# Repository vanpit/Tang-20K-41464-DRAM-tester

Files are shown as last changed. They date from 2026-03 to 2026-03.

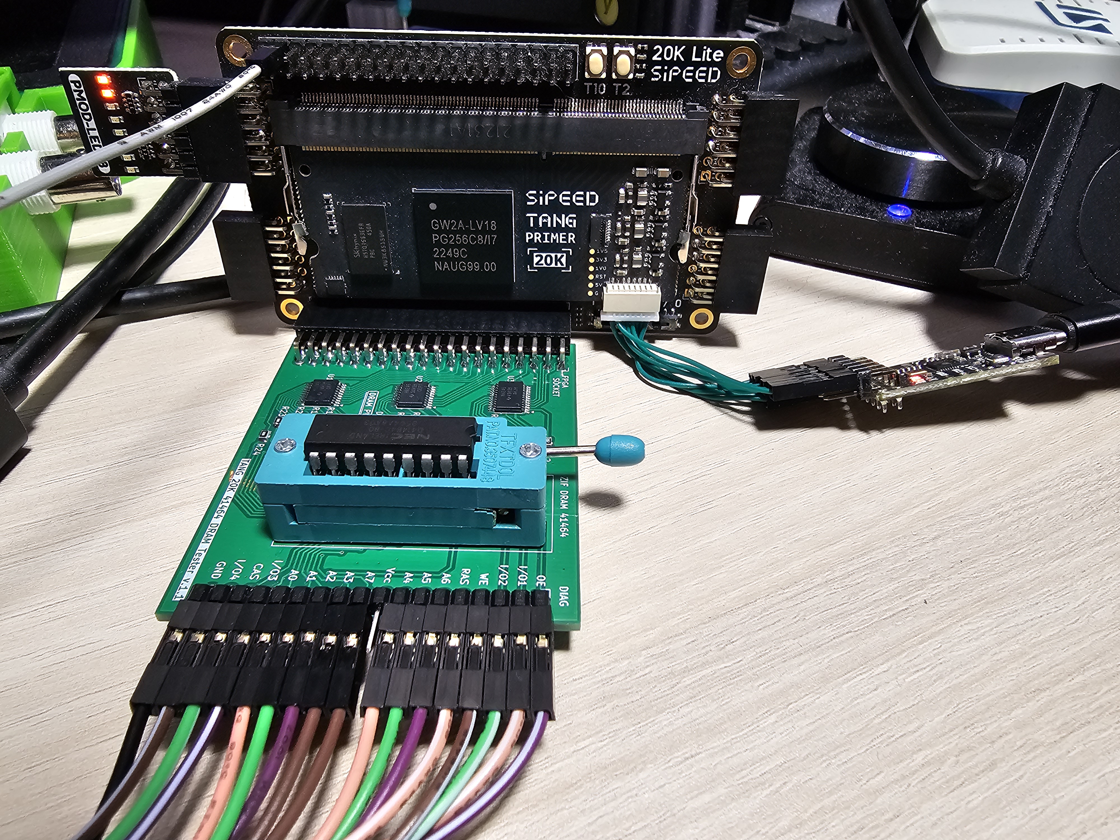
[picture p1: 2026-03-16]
Pictures/20260316_213214.jpg

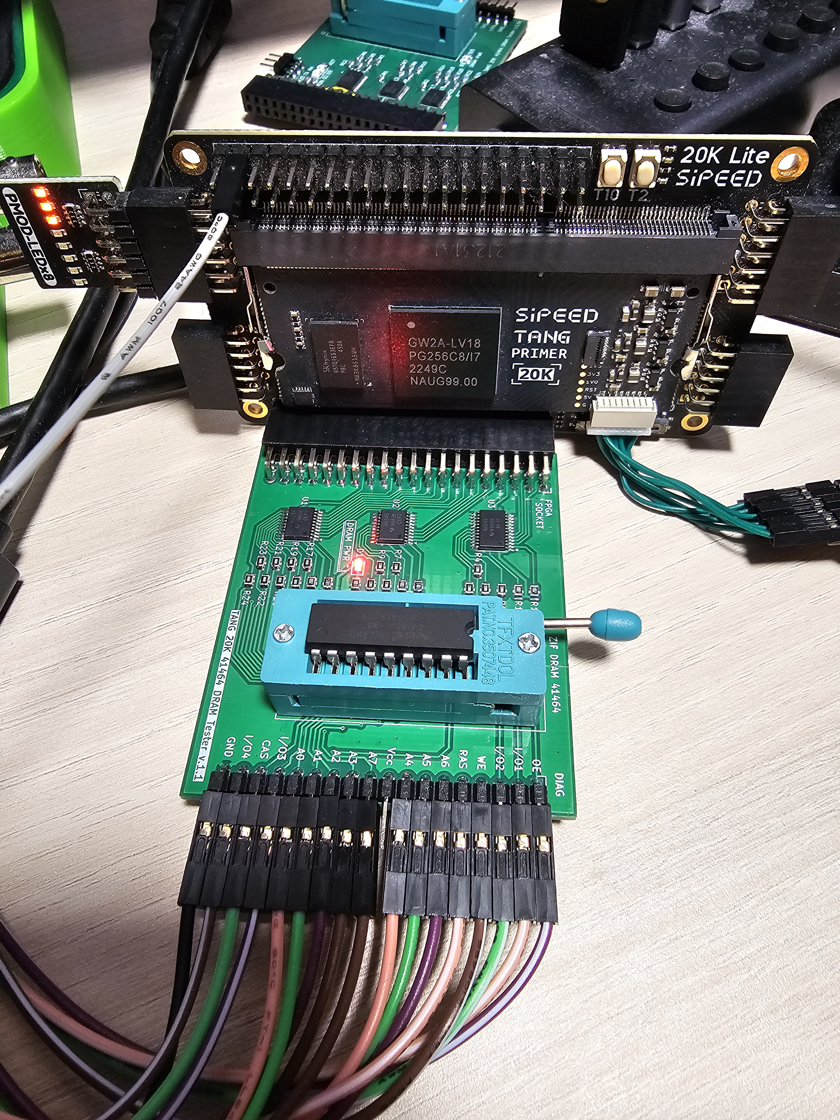
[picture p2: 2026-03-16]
Pictures/20260316_213205.jpg

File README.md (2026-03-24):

Tang Primer 20K & Tang Nano 20K 41464 DRAM Tester

Timing resolution is 5.29ns for Primer 20K version and 6.06ns for Nano 20K version

- 8 different patterns WRITE/READ
- MATS+
- 4ms (datasheet) data retention 

BOM:

- Tang Primer 20K + Lite dock + PMOD LEDx8 module + Sipeed RV Debugger Plus
  - OR
- Tang Nano 20K
  - AND  
- U1, U2: SN74AHCT245PWR
- U3: SN74LVC8T245PW
- U4: MIC94090YC6-TR
- LED SMD 0805 ex. IN-S85CS5R
- R1, R2: 5K Ohm Resistor SMD 0805
- R3..R10: 33 Ohm Resistor SMD 0805
- R11..R14, R16: 10K Ohm Resistor SMD 0805
- R15: 1K Ohm Resistor SMD 0805
- R17..R24: 0 Ohm OR 33 Ohm Resistor SMD 0805
- C1..C7: 100nF 0805 Capacitor
- ZIF Socket 18 pin
- 40 pin (2x20) 90 deg female connector (ZL263-40DG) (Tang Primer only)
- 2x 20 male/female pin headers (Tang Nano only)
- 18 pin (1x18) 90 deg male connector (optional, for debug)

How to use:

- Assembly guide - Pictures
- Synthetize and program Tang with Gowin IDE.
  - For Primer 20K version use "Tang 41464 tester-1.1.zip" gerber files and "Tang 41464 dram tester" firmware project
  - For Nano 20K version use  "Tang 41464 tester Nano 1.1.zip" gerber files and "Tang 41464 dram tester Nano" firmware project
  - IMPORTANT! For Nano 20K version set "pll_clk O0=33M" in BL616 config as project use 10 PIN FPGA 33MHz clock 
- Connect to uart module serial port with 115200 baud rate

Terminal keys
- "1", "2", "3", "4": select dram class speed test 80ns, 100ns, 120ns, 150ns
- "q", "Q": increase/decrease test repetition count (0x03FF reps takes about 10 minutes)
- "w": enable/disable 4ms delay/data retention test between write and read operations
- "c": show current test config
- "r" / lite dock T2 button / Nano 20K S1 button: start test

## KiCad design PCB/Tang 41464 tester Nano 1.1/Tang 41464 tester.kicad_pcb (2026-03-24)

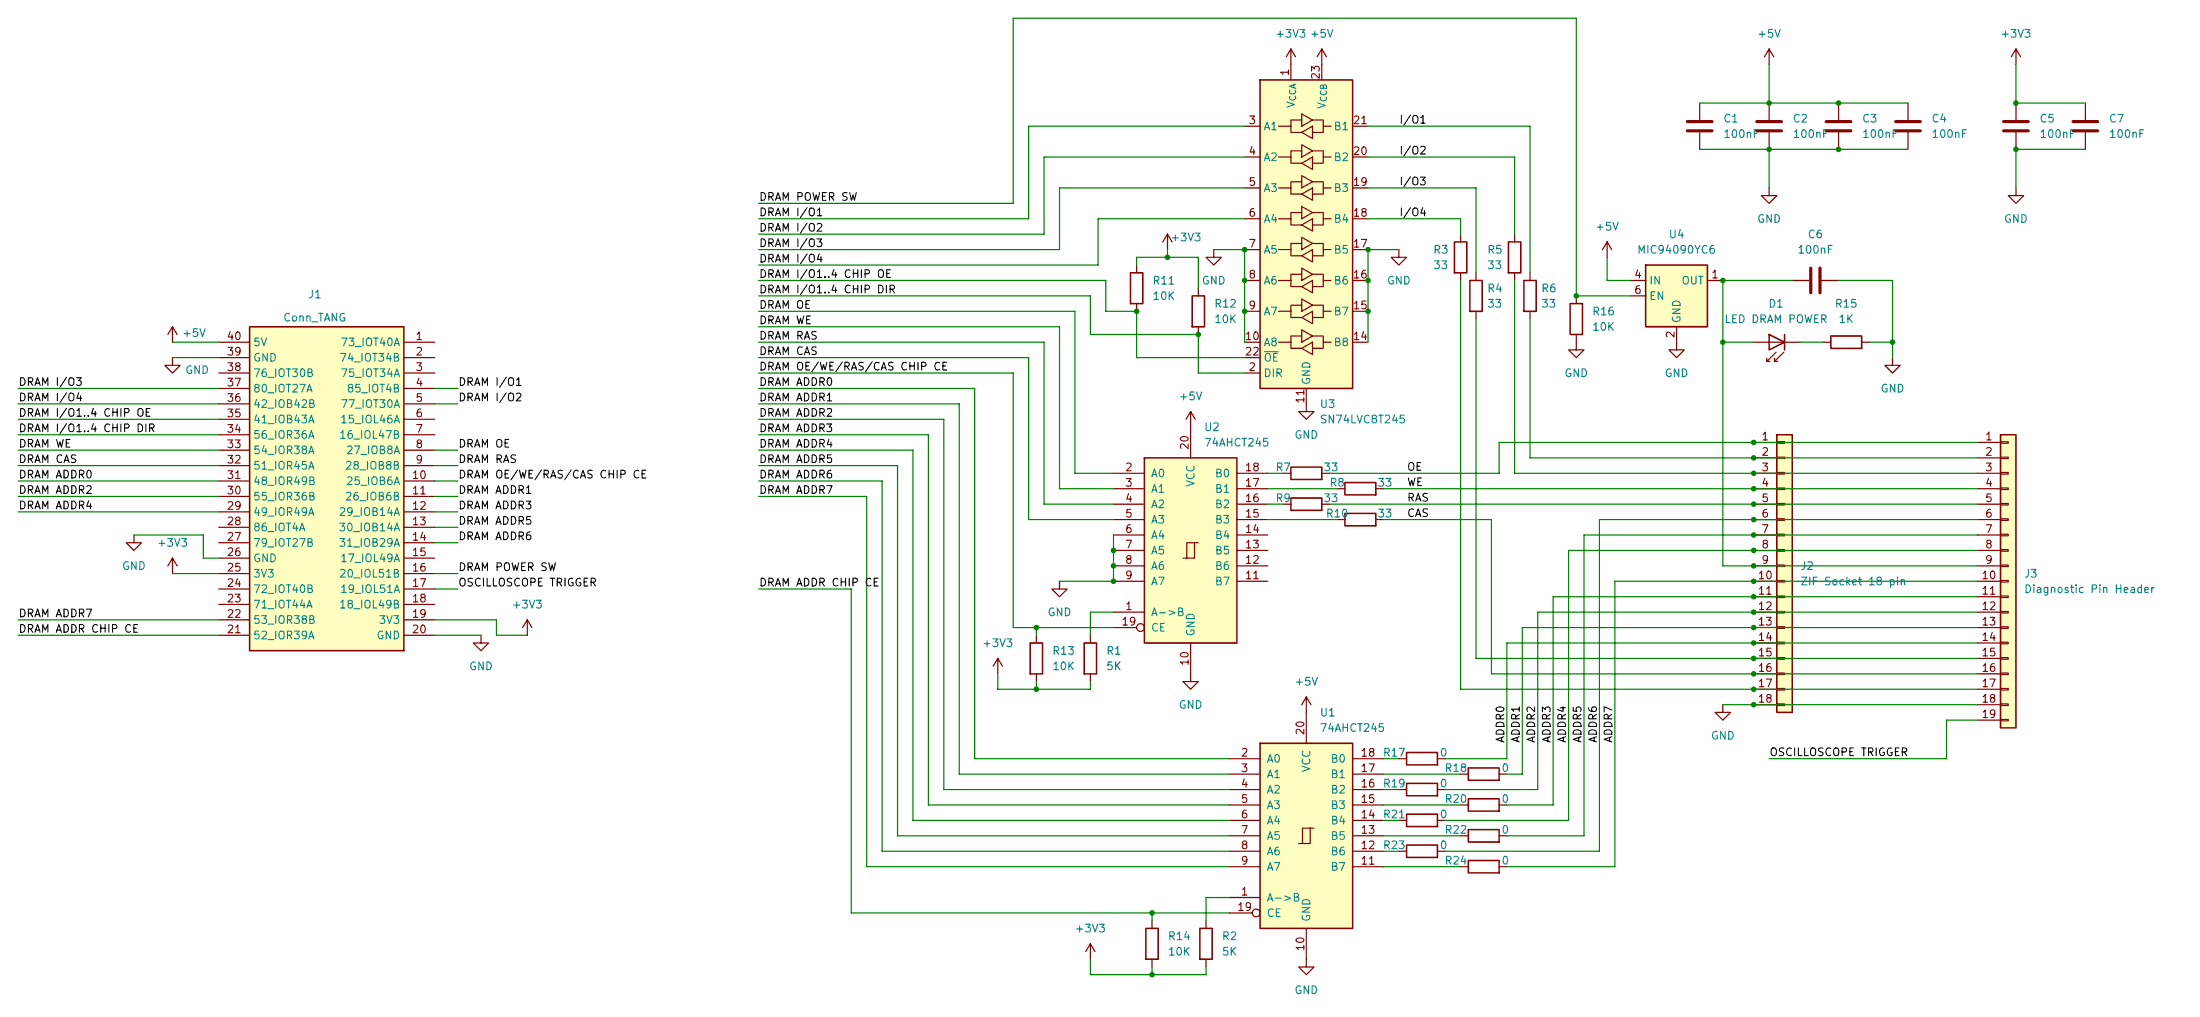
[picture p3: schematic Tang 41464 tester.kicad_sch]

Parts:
C1, C2, C3, C4, C5, C6, C7: 100nF; C_0805_2012Metric
D1: LED DRAM POWER; LED_0805_2012Metric
J1: Conn_TANG; DIP-40_TangNano20K
J2: ZIF Socket 18 pin; DIP-18_W7.62mm_Socket_LongPads
J3: Diagnostic Pin Header; PinHeader_1x19_P2.54mm_Horizontal
R1, R2: 5K; R_0805_2012Metric
R3, R4, R5, R6, R7, R8, R9, R10: 33; R_0805_2012Metric
R11, R12, R13, R14, R16: 10K; R_0805_2012Metric
R15: 1K; R_0805_2012Metric
R17, R18, R19, R20, R21, R22, R23, R24: 0; R_0805_2012Metric
U1, U2: 74AHCT245; TSSOP-20_4.4x6.5mm_P0.65mm
U3: SN74LVC8T245; TSSOP-24_4.4x7.8mm_P0.65mm
U4: MIC94090YC6; SOT-363_SC-70-6

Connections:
+3V3: C5.1, C7.1, J1.19 (3V3), J1.25 (3V3), R1.2, R2.2, R11.1, R12.1, R13.2, R14.2, U3.1 (V_{CCA})
+5V: C1.1, C2.1, C3.1, C4.1, J1.40 (5V), U1.20 (VCC), U2.20 (VCC), U3.23 (V_{CCB}), U3.24 (V_{CCB}), U4.4 (IN)
/ADDR0: J2.14, J3.14, R17.2
/ADDR1: J2.13, J3.13, R18.2
/ADDR2: J2.12, J3.12, R19.2
/ADDR3: J2.11, J3.11, R20.2
/ADDR4: J2.8, J3.8, R21.2
/ADDR5: J2.7, J3.7, R22.2
/ADDR6: J2.6, J3.6, R23.2
/ADDR7: J2.10, J3.10, R24.2
/CAS: J2.16, J3.16, R10.2
/DRAM ADDR0: J1.31 (48_IOR49B), U1.2 (A0)
/DRAM ADDR1: J1.11 (26_IOB6B), U1.3 (A1)
/DRAM ADDR2: J1.30 (55_IOR36B), U1.4 (A2)
/DRAM ADDR3: J1.12 (29_IOB14A), U1.5 (A3)
/DRAM ADDR4: J1.29 (49_IOR49A), U1.6 (A4)
/DRAM ADDR5: J1.13 (30_IOB14A), U1.7 (A5)
/DRAM ADDR6: J1.14 (31_IOB29A), U1.8 (A6)
/DRAM ADDR7: J1.22 (53_IOR38B), U1.9 (A7)
/DRAM ADDR CHIP CE: J1.21 (52_IOR39A), R14.1, U1.19 (CE)
/DRAM CAS: J1.32 (51_IOR45A), U2.5 (A3)
/DRAM I/O1: J1.4 (85_IOT4B), U3.3 (A1)
/DRAM I/O1..4 CHIP DIR: J1.34 (56_IOR36A), R12.2, U3.2 (DIR)
/DRAM I/O1..4 CHIP OE: J1.35 (41_IOB43A), R11.2, U3.22 (~OE)
/DRAM I/O2: J1.5 (77_IOT30A), U3.4 (A2)
/DRAM I/O3: J1.37 (80_IOT27A), U3.5 (A3)
/DRAM I/O4: J1.36 (42_IOB42B), U3.6 (A4)
/DRAM OE: J1.8 (27_IOB8A), U2.2 (A0)
/DRAM OE/WE/RAS/CAS CHIP CE: J1.10 (25_IOB6A), R13.1, U2.19 (CE)
/DRAM POWER SW: J1.16 (20_IOL51B), R16.2, U4.6 (EN)
/DRAM RAS: J1.9 (28_IOB8B), U2.4 (A2)
/DRAM WE: J1.33 (54_IOR38A), U2.3 (A1)
/I/O1: R6.1, U3.21 (B1)
/I/O2: R5.1, U3.20 (B2)
/I/O3: R4.1, U3.19 (B3)
/I/O4: R3.1, U3.18 (B4)
/OE: J2.1, J3.1, R7.2
/OSCILLOSCOPE TRIGGER: J1.17 (19_IOL51A), J3.19
/RAS: J2.5, J3.5, R9.2
/WE: J2.4, J3.4, R8.2
GND: C1.2, C2.2, C3.2, C4.2, C5.2, C6.2, C7.2, J1.20 (GND), J1.26 (GND), J1.39 (GND), J2.18, J3.18, R15.2, R16.1, U1.10 (GND), U2.6 (A4), U2.7 (A5), U2.8 (A6), U2.9 (A7), U2.10 (GND), U3.7 (A5), U3.8 (A6), U3.9 (A7), U3.10 (A8), U3.11 (GND), U3.12 (GND), U3.13 (GND), U3.14 (B8), U3.15 (B7), U3.16 (B6), U3.17 (B5), U4.2 (GND), U4.5 (GND)
unnamed: C6.1, D1.2 (A), J2.9, J3.9, U4.1 (OUT)
unnamed: D1.1 (K), R15.1
unnamed: J2.2, J3.2, R6.2
unnamed: J2.3, J3.3, R5.2
unnamed: J2.15, J3.15, R4.2
unnamed: J2.17, J3.17, R3.2
unnamed: R2.1, U1.1 (A->B)
unnamed: R17.1, U1.18 (B0)
unnamed: R18.1, U1.17 (B1)
unnamed: R19.1, U1.16 (B2)
unnamed: R20.1, U1.15 (B3)
unnamed: R21.1, U1.14 (B4)
unnamed: R22.1, U1.13 (B5)
unnamed: R23.1, U1.12 (B6)
unnamed: R24.1, U1.11 (B7)
unnamed: R1.1, U2.1 (A->B)
unnamed: R7.1, U2.18 (B0)
unnamed: R8.1, U2.17 (B1)
unnamed: R9.1, U2.16 (B2)
unnamed: R10.1, U2.15 (B3)

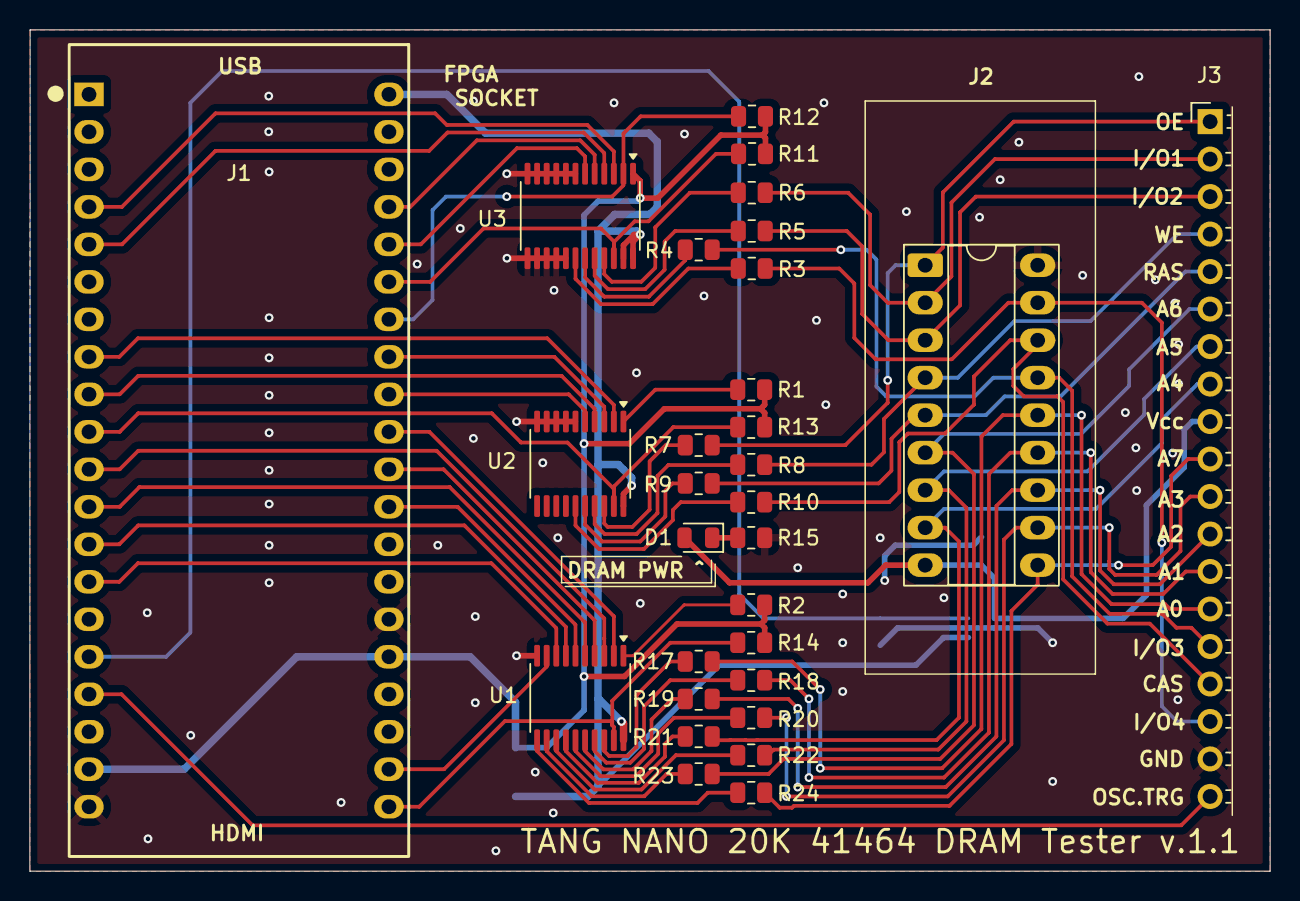
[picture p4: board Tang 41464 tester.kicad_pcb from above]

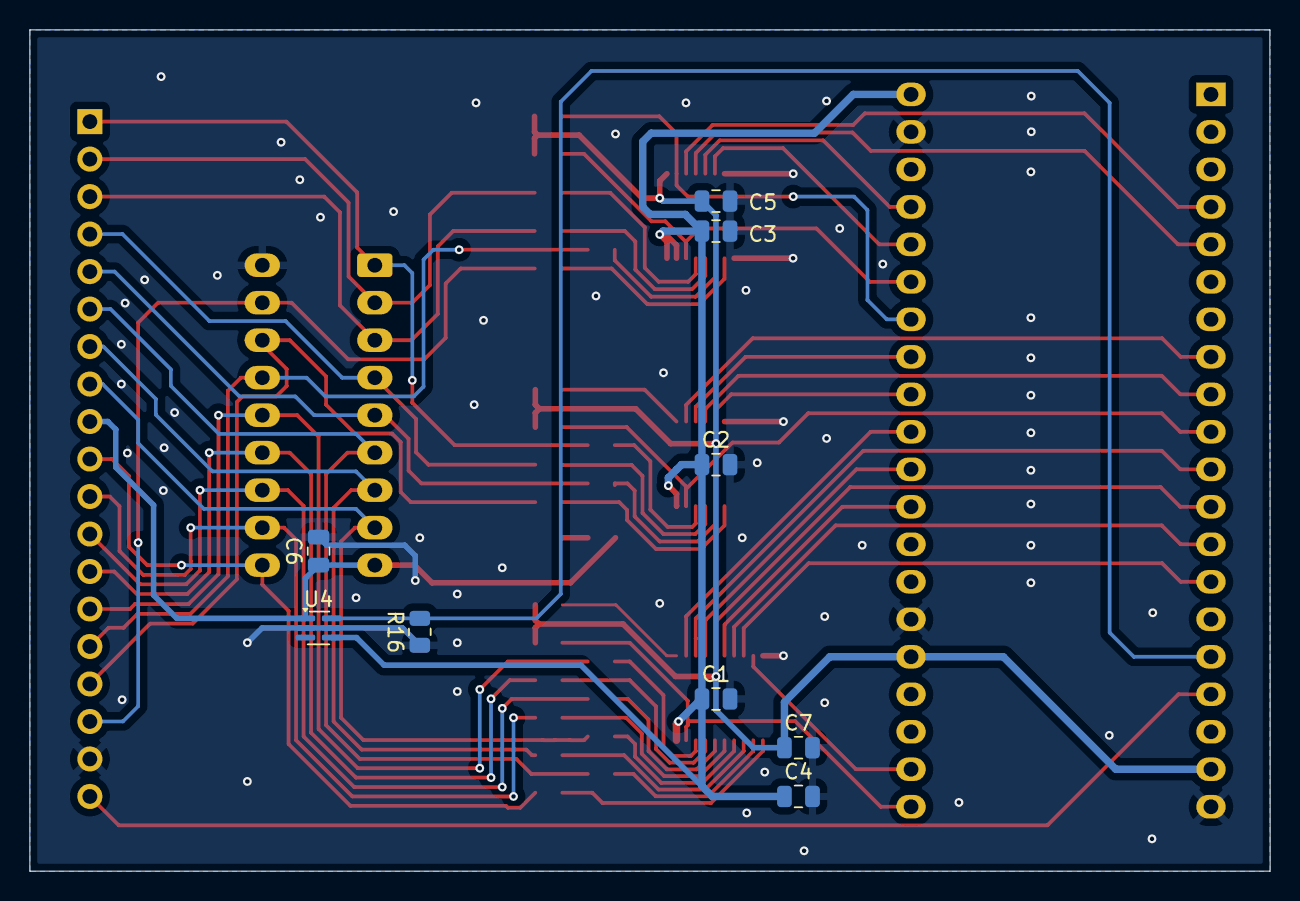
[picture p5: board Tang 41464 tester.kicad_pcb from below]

Board: 2 copper layers, 84.0 x 57.0 mm, 39 parts (9 on the bottom side), 61 nets.

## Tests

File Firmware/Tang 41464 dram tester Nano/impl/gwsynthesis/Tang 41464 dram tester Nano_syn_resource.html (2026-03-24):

# Hierarchy Module Resource

MODULE NAME | REG NUMBER | ALU NUMBER | LUT NUMBER | DSP NUMBER | BSRAM NUMBER | SSRAM NUMBER | ROM16 NUMBER
main (//diskstation-user.home/Piotr/FPGA/Tester Nano/Tang 41464 dram tester Nano/src/main.v) | 166 | - | 447 | 1 | - | - | -
|--button_start_inst (//diskstation-user.home/Piotr/FPGA/Tester Nano/Tang 41464 dram tester Nano/src/main.v) | 25 | - | 43 | - | - | - | -
|--uart_rx_wrapper_inst (//diskstation-user.home/Piotr/FPGA/Tester Nano/Tang 41464 dram tester Nano/src/main.v) | 10 | - | 17 | - | - | - | -
|--uart_rx_inst (//diskstation-user.home/Piotr/FPGA/Tester Nano/Tang 41464 dram tester Nano/src/uart_rx_wrapper.v) | 41 | 3 | 61 | - | - | - | -
|--uart_tx_wrapper_inst (//diskstation-user.home/Piotr/FPGA/Tester Nano/Tang 41464 dram tester Nano/src/main.v) | 38 | - | 363 | - | - | - | -
|--uart_tx_inst (//diskstation-user.home/Piotr/FPGA/Tester Nano/Tang 41464 dram tester Nano/src/uart_tx_wrapper.v) | 31 | 3 | 52 | - | - | - | -
|--dramroutines_inst (//diskstation-user.home/Piotr/FPGA/Tester Nano/Tang 41464 dram tester Nano/src/main.v) | 60 | 11 | 103 | - | - | - | -
|--your_instance_name (//diskstation-user.home/Piotr/FPGA/Tester Nano/Tang 41464 dram tester Nano/src/main.v) | - | - | - | - | - | - | -

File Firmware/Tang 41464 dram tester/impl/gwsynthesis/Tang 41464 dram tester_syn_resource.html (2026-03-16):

# Hierarchy Module Resource

MODULE NAME | REG NUMBER | ALU NUMBER | LUT NUMBER | DSP NUMBER | BSRAM NUMBER | SSRAM NUMBER | ROM16 NUMBER
main (C:/Users/piotr/Documents/FPGA/Tang 41464 dram tester/src/main.v) | 166 | - | 444 | 1 | - | - | -
|--button_start_inst (C:/Users/piotr/Documents/FPGA/Tang 41464 dram tester/src/main.v) | 25 | - | 44 | - | - | - | -
|--uart_rx_wrapper_inst (C:/Users/piotr/Documents/FPGA/Tang 41464 dram tester/src/main.v) | 10 | - | 17 | - | - | - | -
|--uart_rx_inst (C:/Users/piotr/Documents/FPGA/Tang 41464 dram tester/src/uart_rx_wrapper.v) | 41 | 3 | 62 | - | - | - | -
|--uart_tx_wrapper_inst (C:/Users/piotr/Documents/FPGA/Tang 41464 dram tester/src/main.v) | 38 | - | 358 | - | - | - | -
|--uart_tx_inst (C:/Users/piotr/Documents/FPGA/Tang 41464 dram tester/src/uart_tx_wrapper.v) | 31 | 3 | 52 | - | - | - | -
|--dramroutines_inst (C:/Users/piotr/Documents/FPGA/Tang 41464 dram tester/src/main.v) | 60 | 7 | 90 | - | - | - | -
|--your_instance_name (C:/Users/piotr/Documents/FPGA/Tang 41464 dram tester/src/main.v) | - | - | - | - | - | - | -

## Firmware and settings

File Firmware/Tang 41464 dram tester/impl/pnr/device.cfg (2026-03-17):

set JTAG regular_io = false
set SSPI regular_io = false
set MSPI regular_io = false
set READY regular_io = true
set DONE regular_io = true
set I2C regular_io = false
set RECONFIG_N regular_io = false
set unused_pin = default
set CRC_check = true
set compress = false
set encryption = false
set security_bit_enable = true
set bsram_init_fuse_print = true
set background_programming = off
set secure_mode = false
set program_done_bypass = false
set wake_up = 0
set format = binary
set power_on_reset_monitor = true
set multiboot_spi_flash_address = 0x00000000
set vccx = 3.3
set vcc = 1.0

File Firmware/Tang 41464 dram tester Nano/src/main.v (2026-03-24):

module main (
    input wire clk,
    input wire input_button,
    output logic oscilloscope_trigger,
    output logic uart_tx,
    input logic uart_rx,
    output logic dram_power_sw,
    inout wire [3:0] dram_io,
    output logic dram_io_chip_oe,
    output logic dram_io_chip_dir,
    output logic dram_oe,
    output logic dram_we,
    output logic dram_ras,
    output logic dram_cas,
    output logic dram_oe_we_ras_cas_chip_ce,
    output logic [7:0] dram_addr,
    output logic dram_addr_chip_ce,
    output logic led_ok,
    output logic led_fail,
    output logic led_ready
);

import uart_tx_opts_pkg::*;

logic rst_n;
logic [7:0] rst_cnt = '0;

logic clk_dramroutines;
logic pll_lock;

wire btn_start_test;
wire dram_ready;

wire result_ok;
wire result_fail;

localparam logic [15:0] START_TEST_ADDRESS = 16'h0000;                                // test start address
localparam logic [15:0] DRAM_LAST_CELL = 256 * 256 - 1;                               // last DRAM CELL is 256x256 DRAM size minus ONE
//localparam logic [15:0] DRAM_LAST_CELL = START_TEST_ADDRESS + 9 ;                   // last DRAM CELL is 256x256 DRAM size minus ONE

logic [15:0] dram_cell_address;
logic [7:0] row_address;
logic [7:0] col_address;

logic [15:0] dram_cell_linear_counter;
logic [15:0] next_dram_cell_linear_counter;

localparam logic [15:0] ADDR_SEED = 16'h0000;
localparam logic [15:0] ADDR_STEP = 16'h9E37; // musi być nieparzysty

logic test_mode_mats;
logic next_test_mode_mats;
logic [1:0] mats_phase;
logic [1:0] next_mats_phase;

//assign dram_cell_address = dram_cell_linear_counter;
assign dram_cell_address = test_mode_mats
                         ? dram_cell_linear_counter
                         : (ADDR_SEED + dram_cell_linear_counter * ADDR_STEP);

assign row_address = dram_cell_address[15:8];
assign col_address = dram_cell_address[7:0];
logic [7:0] row_address_latch;
logic [7:0] col_address_latch;
logic [7:0] next_row_address_latch;
logic [7:0] next_col_address_latch;

localparam logic [19:0] RETENTION_COUNTER_CYCLES_4MS = 33000 * 4; // 4ms retention interval at 33MHz clock

logic [15:0] warmup_counter;
logic [19:0] retention_test_counter;
logic [19:0] next_retention_test_counter;
logic [3:0] test_data;
logic [3:0] test_data_latch;
logic [3:0] next_test_data_latch;

logic test_read;
logic test_write;
logic test_in_progress;
logic test_completed;

logic next_test_read;
logic next_test_write;
logic next_test_completed;

logic display_result_ok;
logic display_result_fail;
logic reset_results;

logic [2:0] test_pattern_counter;

logic [2:0] next_test_pattern_counter;

logic dram_ready_sync_r;
logic dram_op_pending;
logic next_dram_op_pending;

logic start_test_sequence;

logic result_ok_meta;
logic result_ok_sync;

logic result_fail_meta;
logic result_fail_sync;

logic dram_ready_meta;
logic dram_ready_sync;

logic uart_start_send;
logic [7:0] display_option;

logic uart_tx_busy;

logic [15:0] fail_address;
logic [15:0] next_fail_address;
logic fail_test; // 0 - pattern test fail, 1 - MATS+ test fail
logic next_fail_test; 

wire uart_start_test;
wire uart_show_test_config;
wire uart_inc_repetitions;
wire uart_dec_repetitions;
wire uart_toggle_retention_test;
wire uart_select_speed_00;
wire uart_select_speed_01;
wire uart_select_speed_10;
wire uart_select_speed_11;

logic [1:0] dram_speed_sel, dram_timing_selector;

logic [15:0] repetition_counter;
logic [15:0] next_repetition_counter;
logic [15:0] repetition_counter_selector;

logic use_retention_test;
logic use_retention_test_selector;

logic cycle_completed_pulse;

typedef enum logic [3:0] {
    INIT,
    READ_OP_START,
    READ_OP_COMPLETED,
    WRITE_OP_START,
    WRITE_OP_COMPLETED,
    SWITCH_PATTERN,
    TEST_COMPLETED,
    TEST_FAILED,
    STANDBY
} teststage_t;

teststage_t test_stage;
teststage_t next_test_stage;

localparam logic [3:0] TEST_PATTERNS [0:7] = '{
    4'b0101,
    4'b1010,
    4'b0011,
    4'b1100,
    4'b0110,
    4'b1001,
    4'b1111,
    4'b0000
};

assign test_data =
    dram_cell_address[3:0] ^
    dram_cell_address[7:4] ^
    dram_cell_address[11:8] ^
    dram_cell_address[15:12] ^
    TEST_PATTERNS[test_pattern_counter];

always_ff @(posedge clk)
begin: initresetlogic
    if (rst_cnt == 8'h00)
    begin
        rst_n <= 1'b0;
        rst_cnt <= rst_cnt + 1;
    end else if (rst_cnt == 8'hFF) begin
        rst_n <= 1'b1;
        led_ready <= 1'b0;
    end else begin
        rst_cnt <= rst_cnt + 1'b1;
    end
end


always_ff @(posedge clk or negedge rst_n or negedge pll_lock)
begin: dramsweep
        if (!rst_n || !pll_lock) begin
            reset_results <= 1'b0;
            test_read <= 1'b0;
            test_write <= 1'b0;
            test_in_progress <= 1'b0;
            dram_cell_linear_counter <= 16'h0000;
            display_result_ok <= 1'b0;
            display_result_fail <= 1'b0;
            test_completed <= 1'b0;
            warmup_counter <= 16'h0000;
            test_pattern_counter <= 3'b000;
            dram_op_pending <= 1'b0;
            dram_ready_meta <= 1'b0;
            dram_ready_sync <= 1'b0;
            dram_ready_sync_r <= 1'b0;
            start_test_sequence <= 1'b0;
            result_ok_meta <= 1'b0;
            result_ok_sync <= 1'b0;
            result_fail_meta <= 1'b0;
            result_fail_sync <= 1'b0;
            row_address_latch <= 8'h00;
            col_address_latch <= 8'h00;
            test_data_latch <= 4'h0;
            uart_start_send <= 1'b0;
            dram_speed_sel <= 2'b00;
            dram_timing_selector <= 2'b00;
            repetition_counter <= 16'h0000;
            repetition_counter_selector <= 16'h0000;
            use_retention_test_selector <= 1'b1;
            use_retention_test <= 1'b1;
            retention_test_counter <= 20'h00000;
            display_option <= 8'h00;
            fail_address <= 16'h0000;
            fail_test <= 1'b0;
            test_mode_mats <= 1'b0;
            mats_phase <= 2'b00;
            test_stage <= STANDBY;

        end else begin

            dram_cell_linear_counter <= next_dram_cell_linear_counter;
            test_stage <= next_test_stage;
            test_write <= next_test_write;
            test_read <= next_test_read;
            test_completed <= next_test_completed;
            dram_op_pending <= next_dram_op_pending;
            test_pattern_counter <= next_test_pattern_counter;
            row_address_latch <= next_row_address_latch;
            col_address_latch <= next_col_address_latch;
            test_data_latch <= next_test_data_latch;
            repetition_counter <= next_repetition_counter;
            retention_test_counter <= next_retention_test_counter;
            uart_start_send <= 1'b0;
            test_mode_mats <= next_test_mode_mats;
            mats_phase <= next_mats_phase;
            fail_address <= next_fail_address;
            fail_test <= next_fail_test;

            start_test_sequence <= 1'b0;
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

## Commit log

2026-03-16 Add README for Tang Primer DRAM Tester
    Added detailed information about the Tang Primer DRAM Tester, including BOM, usage instructions, and terminal keys.
2026-03-16 Update BOM with new module details
2026-03-16 Update README with ZIF socket and connector details
    Added information about ZIF socket and connectors.
2026-03-17 Update BOM components in README.md
2026-03-17 Gerber files added
2026-03-17 Fix typo in resistor value from 'O' to '0'
2026-03-17 Cleanup repo
    [device.cfg]
2026-03-24 Added tester Nano version for Tang 20K Nano FPGA
    [Tang 41464 tester-B_Cu.gbl, Tang 41464 tester-B_Mask.gbs, Tang 41464 tester-B_Paste.gbp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]
2026-03-24 Correct gerber upload for Nano version
    [Tang 41464 tester-B_Cu.gbl, Tang 41464 tester-B_Mask.gbs, Tang 41464 tester-B_Paste.gbp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]
2026-03-24 Revise README for Tang Primer and Nano 20K details
    Updated README with details for Tang Primer 20K and Nano 20K DRAM Tester, including timing resolution, BOM changes, and usage instructions.
2026-03-24 Fix formatting of BOM section in README
